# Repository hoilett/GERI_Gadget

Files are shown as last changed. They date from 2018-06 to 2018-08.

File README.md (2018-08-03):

# GERI_Gadget (under development so bookmark this page and stay tuned!)

<p align="center">
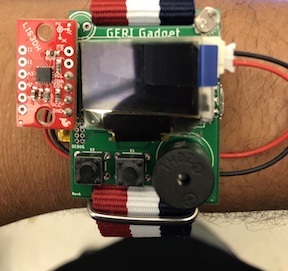
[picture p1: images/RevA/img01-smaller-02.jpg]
GERI Gadget Rev A
  
</p>

The GERI Gadget is a small smartwatch I made for students taking my Biomedical Instrumentation class during GERI Summer Residential 2018. GERI stands for Gifted Education Resource Institute and it's a wonderful group at Purdue that specializes on educational policy, training, teaching methods, etc. of gifted students in K-12. Check out all their wonderful work on their website: [Purdue GERI](https://www.education.purdue.edu/geri/)

Anyways, I wanted to create a device that allowed students to get hands-on experience building some sort of Biomedical device. This meant adding enough peripherals so that students could make anything from a pedometer to even a fall alert. Revision A of the watch contains a few peripherals, namely:
* ATSAMD21 Microcontroller
* On/Off Switch
* Battery Charging Circuit
* OLED
* Two pushbuttons
* Buzzer
* Photoresistor
* LED
* LIS3DH Accelerometer

_**This section is still under development. I will be filling it out over the next few weeks so bookmark this page and stay tuned!**_

## Programming the Microcontroller
###### **A. Installing the board definitions for SparkFun's SAMD21 Dev Breakout Board**
###### **B. Installing the proper code libraries**
You will need three libraries to get started with the GERI Gadget:
1. Adafruit's SSD1306 Library
2. Adafruit's GFX Library
3. SparkFun's LIS3DH Accelerometer Library

## Advanced Setup Instructions
## 1. Assembling the printed circuit board
## 2. Booloading the ATSAMD21

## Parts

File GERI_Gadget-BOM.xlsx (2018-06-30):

GERI Gadget Rev A BOM |  |  |  |  |  |  |  |  |  |  |  | 14 | $25.45 | $356.26 | $21.15 | $22.72 | $318.41 | Totals
BOM # | Comment | Designator | Description | Mounting Type | Package | Manufacturer | Manufacturer Part Number | Supplier | Supplier Part Number | Price per unit | Quantity per Student | Class Quantity (x14) | Total per Student | Class Total | $ per 10 units | $ per 10 units per Student | $ Class total in bulk
1 | SAMD21 | Arduino | ARM® Cortex®-M0+ SAM D21G Microcontroller IC 32-Bit 48MHz 256KB (256K x 8) FLASH 48-TQFP (7x7) | smd | 48-TQFP | Microchip Technology | ATSAMD21G18A-AU | Digikey.com | ATSAMD21G18A-AU-ND | $3.15 | 1 | 14 | $3.15 | $44.10 | $3.15 | $3.15 | $44.10
2 | OLED | OLED | Datasheet 128x64 OLED Module SPI 0.96"Graphic Displays,White on Black | SMD |  | EastRising | ER-OLED0.96-1W | BuyDisplay.com | https://www.buydisplay.com/default/datasheet-128x64-oled-module-spi-0-96-inch-graphic-displays-white-on-black | $3.25 | 1 | 14 | $3.25 | $45.50 | $3.25 | $3.25 | $45.50
3 | MCP6001 | OP1 | General Purpose Amplifier 1 Circuit Rail-to-Rail SOT-23-5 | SMD | SOT-23-5 | Microchip Technology | MCP6001T-I/OT | Digikey.com | MCP6001T-I/OTCT-ND | $0.25 | 1 | 14 | $0.25 | $3.50 | $0.25 | $0.25 | $3.50
4 | Accelerometer | Accel | SparkFun Triple Axis Accelerometer Breakout - LIS3DH | THT |  | SparkFun Electronics | SEN-13963 | SparkFun.com | SEN-13963 | $4.95 | 1 | 14 | $4.95 | $69.30 | $4.95 | $4.95 | $69.30
5 | N-FET |  | N-Channel 60V 260mA (Ta) 300mW (Ta) Surface Mount SOT-23-3 (TO-236) | SMD | SOT-23-3 | ON Semiconductor | NTR5103NT1G | Digikey.com | NTR5103NT1GOSCT-ND | $0.18 | 2 | 28 | $0.36 | $5.04 | $0.16 | $0.32 | $4.51
6 | 400mAh LiPo Battery |  | 3.7V Lithium-Ion Battery Rechargeable (Secondary) 400mAh | JST |  | SparkFun Electronics | PRT-13851 | Digikey.com | 1568-1493-ND | $4.95 | 1 | 14 | $4.95 | $69.30 | $4.95 | $4.95 | $69.30
7 | JST Connector | LIPO | JST Right Angle Connector - White | SMD | NA | 4UCOM Technology Inc. |  | SparkFun.com | PRT-08612 | $0.95 | 1 | 14 | $0.95 | $13.30 | $0.95 | $0.95 | $13.30
8 | MCP73831 | CHRG | Charger IC Lithium-Ion/Polymer SOT-23-5 | SMD | SOT-23-5 | Microchip Technology | MCP73831T-2ACI/OT | Digikey.com | MCP73831T-2ACI/OTCT-ND | $0.58 | 1 | 14 | $0.58 | $8.12 | $0.58 | $0.58 | $8.12
9 | MIC5501-3V | LDO | Linear Voltage Regulator IC Positive Fixed 1 Output 3V 300mA SOT-23-5 | SMD | SOT-23-5 | Microchip Technology | MIC5501-3.0YM5-TR | Digikey.com | 576-4905-1-ND | $0.11 | 1 | 14 | $0.11 | $1.54 | $0.11 | $0.11 | $1.54
10 | Micro USB Female | USB | USB - micro B USB 2.0 Receptacle Connector 5 Position Surface Mount, Right Angle | SMD | 5-Pin-USB-Micro | Amphenol FCI | 10118192-0001LF | Digikey.com | 609-4613-1-ND | $0.46 | 1 | 14 | $0.46 | $6.44 | $0.39 | $0.39 | $5.50
11 | Schottky Diode | D3,D4 | Diode Schottky 30V 1.5A Surface Mount USC | SMD | USC | Toshiba Semiconductor and Storage | CUS15S30,H3F | Digikey.com | CUS15S30H3FCT-ND | $0.43 | 3 | 42 | $1.29 | $18.06 | $0.31 | $0.93 | $13.06
12 | Switch | SWITCH | SWITCH SLIDE DPDT 300MA 6V | SMD | J Lead | C&K | JS202011JCQN | Digikey.com | CKN10723CT-ND | $0.48 | 1 | 14 | $0.48 | $6.72 | $0.46 | $0.46 | $6.48
13 | 15pF capacitor |  | 15pF ±5% 16V Ceramic Capacitor C0G, NP0 0402 (1005 Metric) | SMD | 0402 | Wurth Electronics Inc. | 885012005026 | Digikey.com | 732-7442-1-ND | $0.10 | 2 | 28 | $0.20 | $2.80 | $0.01 | $0.03 | $0.42
14 | 32.768kHz Crystal | Y1,XTAL1 | 32.768kHz ±10ppm Crystal 12.5pF 90 kOhms 2-SMD, No Lead | SMD | 2-SMD, No Lead | ECS Inc. | ECS-.327-12.5-12-C-TR | Digikey.com | XC2288CT-ND | $0.74 | 1 | 14 | $0.74 | $10.36 | $0.74 | $0.74 | $10.36
15 | Inductor | L1 | FERRITE BEAD 220 OHM 0603 1LN | SMD | 0603 | Samsung Electro-Mechanics | CIS10P221NC | Digikey.com | 1276-6350-1-ND | $0.10 | 1 | 14 | $0.10 | $1.40 | $0.10 | $0.10 | $1.40
16 | 40-pos, Male Headers |  | Connector Header Through Hole 40 position 0.100" (2.54mm) | THT |  | Sullins Connector Solutions | PREC040SAAN-RC | Digikey.com | S1012EC-40-ND | $0.51 | 0.25 | 3.5 | $0.13 | $1.79 | $0.51 | $0.10 | $1.79
 | 2.2uF capacitor | C1,C2,C4,C5,C8 | 2.2µF ±20% 10V Ceramic Capacitor X5R 0603 (1608 Metric) | SMD | 0603 | Wurth Electronics Inc. | 885012106011 | Digi-Key | 732-7908-1-ND | $0.10 | 6 | 84 | $0.60 | $8.40 | $0.06 | $0.36 | $5.04
 | 1.02k resistor | R1,R2,R3 | RES SMD 1.02K OHM 1% 1/16W 0402 | SMD | 0402 | Yageo | RC0402FR-071K02L | Digi-Key | YAG3029CT-ND | $0.10 | 4 | 56 | $0.40 | $5.60 | $0.01 | $0.05 | $0.73
 | 10.2k resistor | R3 | 10.2k Ohm ±1% 0.063W, 1/16W Chip Resistor 0402 (1005 Metric) Moisture Resistant Thick Film | SMD | 0402 | Yageo | RC0402FR-0710K2L | Digi-Key | YAG2950CT-ND | $0.10 | 6 | 84 | $0.60 | $8.40 | $0.01 | $0.08 | $1.09
 | 390k resistor
 | 100n capacitor | C3,C5,C7,C8,C9 | 0.1µF ±20% 10V Ceramic Capacitor X5R 0402 (1005 Metric) | SMD | 0402 | KEMET | C0402C104M8PACTU | Digi-Key | 399-7764-1-ND | $0.10 | 8 | 112 | $0.80 | $11.20 | $0.03 | $0.20 | $2.80
 | 10uF capacitor |  | 10µF ±20% 10V Ceramic Capacitor X5R 0603 (1608 Metric) | SMD | 0603 | Taiyo Yuden | LMK107BBJ106MALT | Digi-Key | 587-3258-1-ND | $0.22 | 5 | 70 | $1.10 | $15.40 | $0.15 | $0.76 | $10.57

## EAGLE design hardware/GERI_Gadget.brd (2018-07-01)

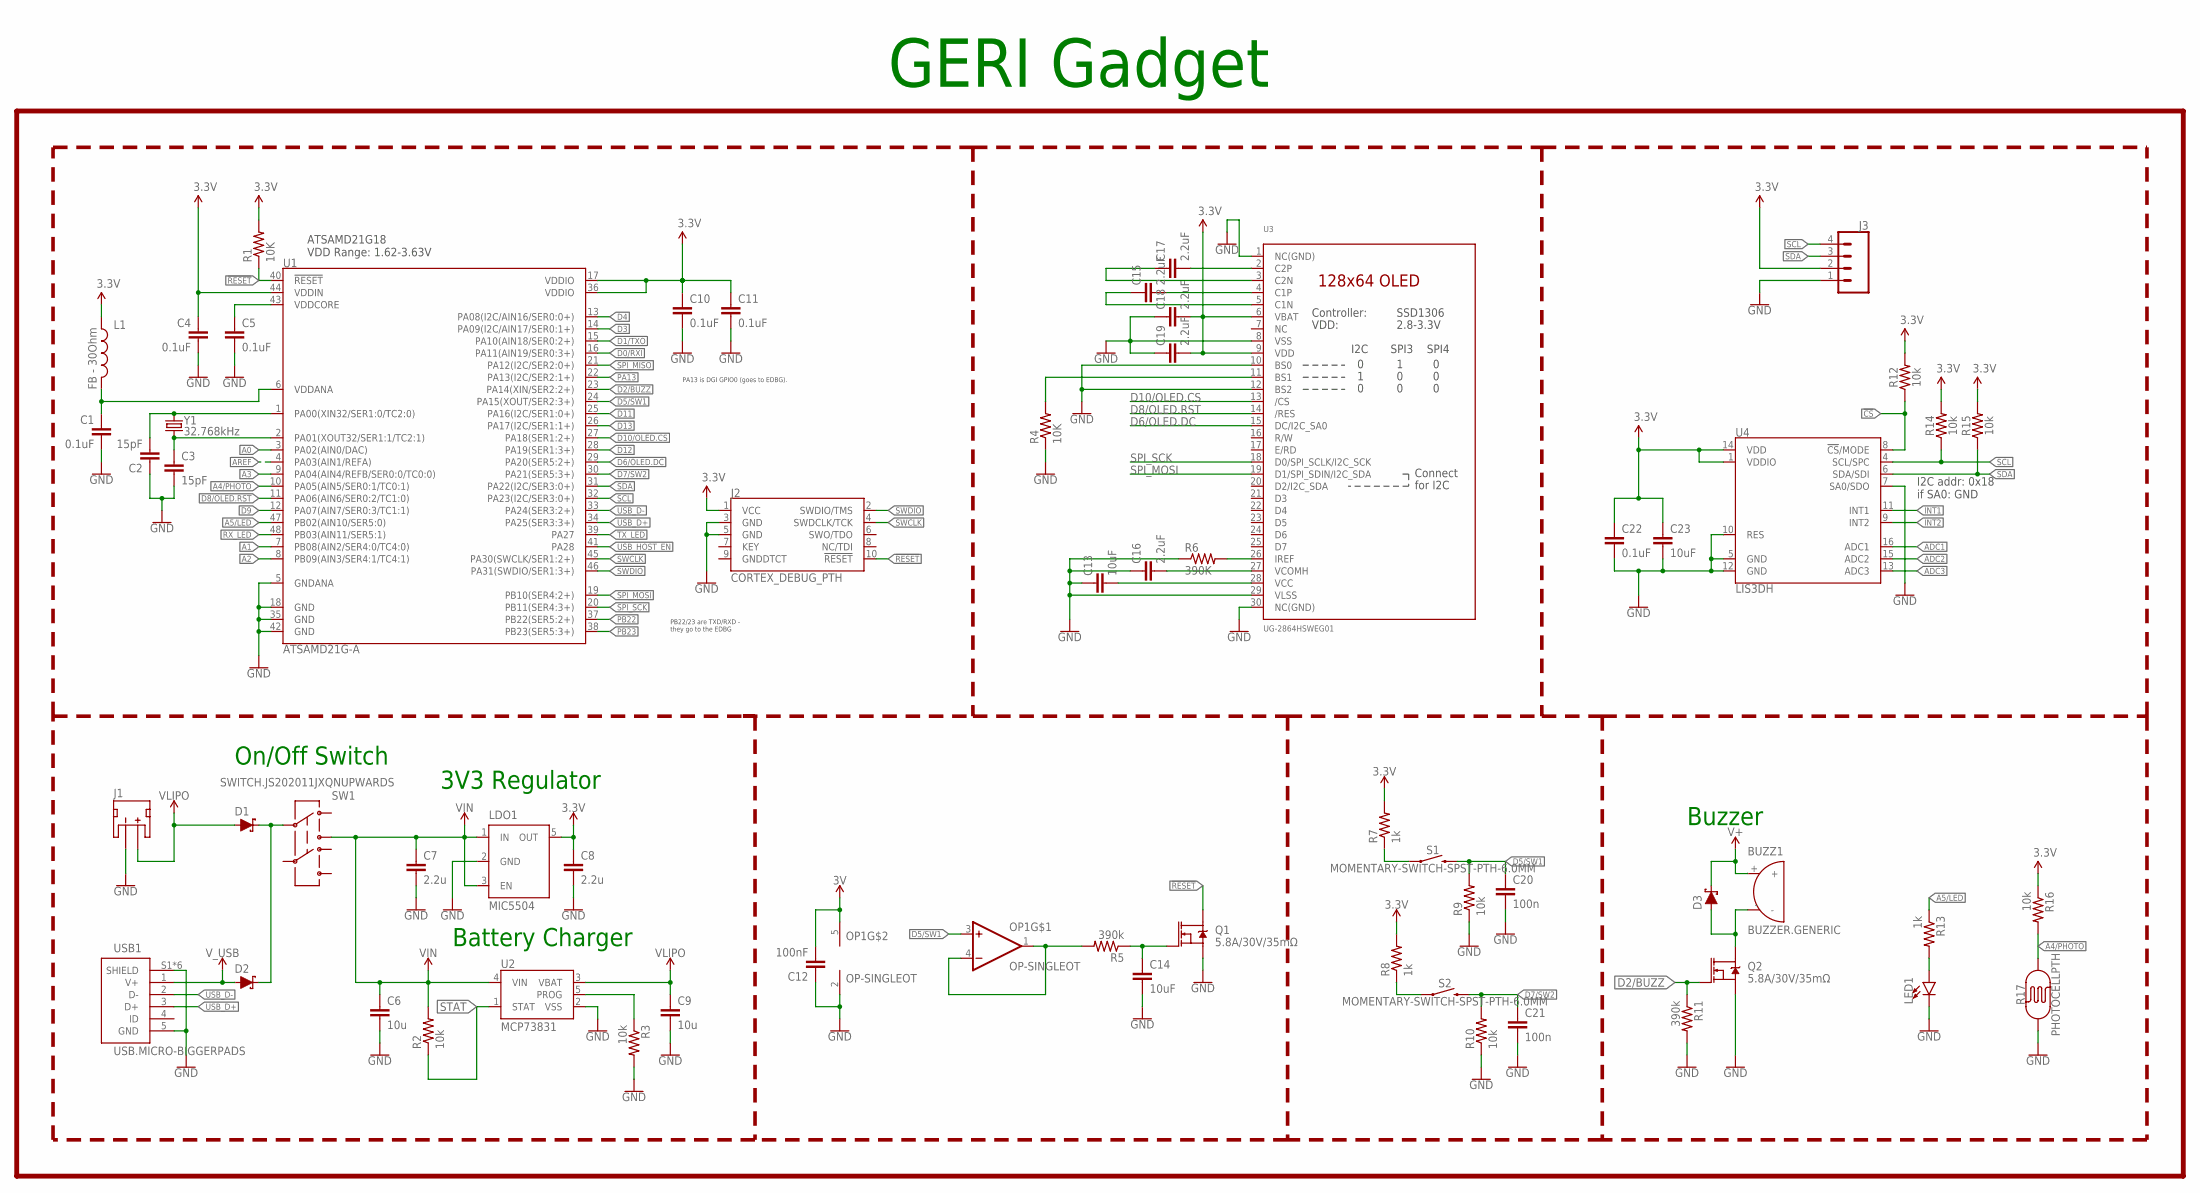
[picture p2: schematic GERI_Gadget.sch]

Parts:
BUZZ1: BUZZER.GENERIC; PIEZO-1
C1, C4, C5, C10, C11: 0.1uF; C0402
C2, C3: 15pF; C0402
C6, C9: 10u; C0603
C7, C8: 2.2u; C0603
C12: 100nF; C0402
C13, C14: 10uF; C0603
C15, C16, C17, C18, C19: 2.2uF; C0603
C20, C21: 100n; C0402
C22: 0.1uF; 0402
C23: 10uF; 0603
D1, D2, D3: SCHOTTKY-USC; USC
J1: JST_2MM_MALE; JST-2-SMD
J2: CORTEX_DEBUG_PTH; 2X5-PTH-1.27MM
J3: CONN_04; 1X04
L1: FB - 30Ohm; 0603
LDO1: MIC5504; SOT23-5
LED1: LED5MM; LED_5MM
OP1: OP-SINGLEOT; SOT23-5
Q1, Q2: 5.8A/30V/35mΩ; SOT23-3
R1, R4: 10K; R0402-BIGGER
R2, R3, R9, R10, R16: 10k; R0402-BIGGER
R5, R11: 390k; R0402-BIGGER
R6: 390K; R0402-BIGGER
R7, R8, R13: 1k; R0402-BIGGER
R12, R14, R15: 10k; 0402
R17: PHOTOCELLPTH; PHOTOCELL
REV1: REVISION.A; REV.A
S1, S2: MOMENTARY-SWITCH-SPST-PTH-6.0MM; TACTILE_SWITCH_PTH_6.0MM
SW1: SWITCH.JS202011JXQNUPWARDS; SWITCH.00
U1: ATSAMD21G-A; TQFP-48
U2: MCP73831; SOT23-5
U3: UG-2864HSWEG01; UG-2864HSWEG01_0.96IN_NO-WRAPAROUND
U4: LIS3DH; LGA-16-3X3
USB1: USB.MICRO-BIGGERPADS; USB-MICRO-01.BIGGERPADS
Y1: 32.768kHz; CRYSTAL-SMD-3.2X1.5MM

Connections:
3.3V: C4.1, C8.1, C10.1, C11.1, C18.2, C19.2, C22.1, C23.1, J2.1 (VCC), J3.2, L1.1, LDO1.5 (OUT), R1.2, R7.2, R8.2, R12.2, R14.2, R15.2, R16.1, U1.17 (VDDIO), U1.36 (VDDIO), U1.44 (VDDIN), U3.6 (VBAT), U3.9 (VDD), U4.1 (VDDIO), U4.14 (VDD)
3V: C12.2, OP1.5 (V+)
!CS: R12.1, U4.8 (!CS!/MODE)
!RESET: J2.10 (!RESET), Q1.3 (D), R1.1, U1.40 (!RESET!)
A0: U1.3 (PA02(AIN0/DAC))
A1: U1.7 (PB08(AIN2/SER4:0/TC4:0))
A2: U1.8 (PB09(AIN3/SER4:1/TC4:1))
A3: U1.9 (PA04(AIN4/REFB/SER0:0/TC0:0))
A4/PHOTO: R16.2, R17.2, U1.10 (PA05(AIN5/SER0:1/TC0:1))
A5/LED: R13.1, U1.47 (PB02(AIN10/SER5:0))
ADC1: U4.16 (ADC1)
ADC2: U4.15 (ADC2)
ADC3: U4.13 (ADC3)
AREF: U1.4 (PA03(AIN1/REFA))
D0/RXI: U1.16 (PA11(AIN19/SER0:3+))
D1/TXO: U1.15 (PA10(AIN18/SER0:2+))
D2/BUZZ: Q2.1 (G), R11.1, U1.23 (PA14(XIN/SER2:2+))
D3: U1.14 (PA09(I2C/AIN17/SER0:1+))
D4: U1.13 (PA08(I2C/AIN16/SER0:0+))
D5/SW1: C20.1, OP1.3 (+IN), R9.2, S1.3 (2), U1.24 (PA15(XOUT/SER2:3+))
D6/OLED.DC: U1.29 (PA20(SER5:2+)), U3.15 (DC/I2C_SA0)
D7/SW2: C21.1, R10.2, S2.3 (2), U1.30 (PA21(SER5:3+))
D8/OLED.RST: U1.11 (PA06(AIN6/SER0:2/TC1:0)), U3.14 (/RES)
D9: U1.12 (PA07(AIN7/SER0:3/TC1:1))
D10/OLED.CS: U1.27 (PA18(SER1:2+)), U3.13 (/CS)
D11: U1.25 (PA16(I2C/SER1:0+))
D12: U1.28 (PA19(SER1:3+))
D13: U1.26 (PA17(I2C/SER1:1+))
GND: C1.2, C2.1, C3.2, C4.2, C5.2, C6.2, C7.2, C8.2, C9.2, C10.2, C11.2, C12.1, C13.1, C14.2, C16.1, C18.1, C19.1, C20.2, C21.2, C22.2, C23.2, J1.1 (-), J2.3 (GND), J2.5 (GND), J3.1, LDO1.2 (GND), LED1.K (C), OP1.2 (V-), Q1.2 (S), Q2.2 (S), R3.2, R4.1, R6.1, R9.1, R10.1, R11.2, R17.1, U1.5 (GNDANA), U1.18 (GND), U1.35 (GND), U1.42 (GND), U2.2 (VSS), U3.1 (NC(GND)), U3.8 (VSS), U3.10 (BS0), U3.12 (BS2), U3.29 (VLSS), U3.30 (NC(GND)), U4.5 (GND), U4.7 (SA0/SDO), U4.10 (RES), U4.12 (GND), USB1.5 (GND), USB1.S1 (SHIELD), USB1.S2 (SHIELD), USB1.S3 (SHIELD), USB1.S4 (SHIELD), USB1.S5 (SHIELD), USB1.S6 (SHIELD)
INT1: U4.11 (INT1)
INT2: U4.9 (INT2)
unnamed: C2.2, U1.1 (PA00(XIN32/SER1:0/TC2:0)), Y1.P$2 (2)
unnamed: LED1.A, R13.2
unnamed: C3.1, U1.2 (PA01(XOUT32/SER1:1/TC2:1)), Y1.P$1 (1)
unnamed: OP1.1 (OUT), OP1.4 (-IN), R5.2
unnamed: R7.1, S1.1
unnamed: R8.1, S2.1
unnamed: R3.1, U2.5 (PROG)
unnamed: D1.- (C), D2.- (C), SW1.2
unnamed: C14.1, Q1.1 (G), R5.1
unnamed: R4.2, U3.11 (BS1)
unnamed: BUZZ1.-, D3.+ (A), Q2.3 (D)
unnamed: R6.2, U3.26 (IREF)
unnamed: C17.2, U3.2 (C2P)
unnamed: C17.1, U3.3 (C2N)
unnamed: C15.2, U3.4 (C1P)
unnamed: C15.1, U3.5 (C1N)
unnamed: C13.2, U3.28 (VCC)
unnamed: C16.2, U3.27 (VCOMH)
PA13: U1.22 (PA13(I2C/SER2:1+))
PB22: U1.37 (PB22(SER5:2+))
PB23: U1.38 (PB23(SER5:3+))
RX_LED: U1.48 (PB03(AIN11/SER5:1))
SCL: J3.4, R14.1, U1.32 (PA23(I2C/SER3:0+)), U4.4 (SCL/SPC)
SDA: J3.3, R15.1, U1.31 (PA22(I2C/SER3:0+)), U4.6 (SDA/SDI)
SPI_MISO: U1.21 (PA12(I2C/SER2:0+))
SPI_MOSI: U1.19 (PB10(SER4:2+)), U3.19 (D1/SPI_SDIN/I2C_SDA)
SPI_SCK: U1.20 (PB11(SER4:3+)), U3.18 (D0/SPI_SCLK/I2C_SCK)
STAT: R2.1, U2.1 (STAT)
SWCLK: J2.4 (SWDCLK/TCK), U1.45 (PA30(SWCLK/SER1:2+))
SWDIO: J2.2 (SWDIO/TMS), U1.46 (PA31(SWDIO/SER1:3+))
TX_LED: U1.39 (PA27)
USB_D+: U1.34 (PA25(SER3:3+)), USB1.3 (D+)
USB_D-: U1.33 (PA24(SER3:2+)), USB1.2 (D-)
USB_HOST_EN: U1.41 (PA28)
V+: BUZZ1.+, D3.- (C)
VDDANA: C1.1, L1.2, U1.6 (VDDANA)
VDDCORE: C5.1, U1.43 (VDDCORE)
VIN: C6.1, C7.1, LDO1.1 (IN), LDO1.3 (EN), R2.2, SW1.3, U2.4 (VIN)
VLIPO: C9.1, D1.+ (A), J1.2 (+), U2.3 (VBAT)
V_USB: D2.+ (A), USB1.1 (V+)

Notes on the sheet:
PB22/23 are TXD/RXD - they go to the EDBG
PA13 is DGI GPIO0 (goes to EDBG).
ATSAMD21G18 VDD Range: 1.62-3.63V
3V3 Regulator
On/Off Switch
Battery Charger
Buzzer
I2C addr: 0x18 if SA0: GND
GERI Gadget

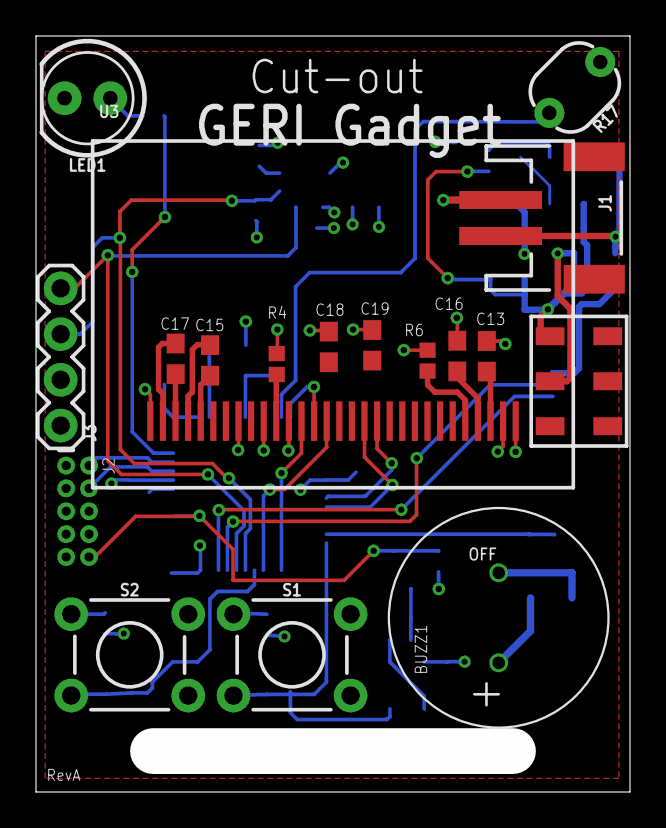
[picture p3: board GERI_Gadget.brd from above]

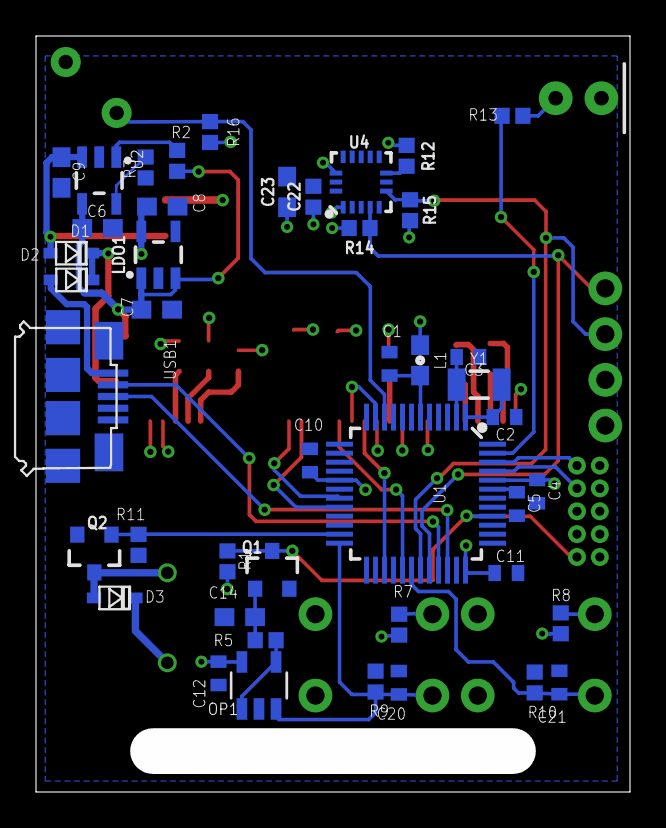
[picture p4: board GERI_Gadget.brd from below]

Board: 2 copper layers, 33.0 x 42.0 mm, 63 parts (44 on the bottom side), 46 nets.

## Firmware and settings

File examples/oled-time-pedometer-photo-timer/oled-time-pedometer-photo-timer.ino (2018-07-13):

#include <SPI.h>
#include <Wire.h>
#include <Adafruit_GFX.h>
#include <Adafruit_SSD1306.h>

// Uncomment this block to use hardware SPI
#define OLED_DC     6
#define OLED_CS     10
#define OLED_RESET  8
Adafruit_SSD1306 display(OLED_DC, OLED_RESET, OLED_CS);

#define NUMFLAKES 10
#define XPOS 0
#define YPOS 1
#define DELTAY 2

#define LOGO16_GLCD_HEIGHT 16 
#define LOGO16_GLCD_WIDTH  16 
static const unsigned char PROGMEM logo16_glcd_bmp[] =
{ B00000000, B11000000,
  B00000001, B11000000,
  B00000001, B11000000,
  B00000011, B11100000,
  B11110011, B11100000,
  B11111110, B11111000,
  B01111110, B11111111,
  B00110011, B10011111,
  B00011111, B11111100,
  B00001101, B01110000,
  B00011011, B10100000,
  B00111111, B11100000,
  B00111111, B11110000,
  B01111100, B11110000,
  B01110000, B01110000,
  B00000000, B00110000 };

#if (SSD1306_LCDHEIGHT != 64)
#error("Height incorrect, please fix Adafruit_SSD1306.h!");
#endif

//this is for the screen
int screenNumber = 0;


//This is for the pedometer
#include "SparkFunLIS3DH.h"
#include "Wire.h"
#include "SPI.h"
LIS3DH myIMU; //Default constructor is I2C, addr 0x19.
unsigned long steps = 0;


//This is for the time
#include <RTCZero.h>
RTCZero rtc;
/* Change these values to set the current initial time */
const byte seconds = 0;
const byte minutes = 7;
const byte hours = 10;

/* Change these values to set the current initial date */
const byte day = 15;
const byte month = 6;
const byte year = 15;


//this is for the graph
int xaxis = 0;


//this is for the timer
unsigned long counter = 0;
unsigned long startTime = 0;

void setup()   {                
  SerialUSB.begin(9600);


  //this is for the display
  display.begin(SSD1306_SWITCHCAPVCC);
  display.display();
  delay(2000);
  display.clearDisplay();


  //this is for the time
  rtc.begin();
  rtc.setTime(hours, minutes, seconds);
  rtc.setDate(day, month, year);


  //this is for the step counter / pedometer
  myIMU.begin();
}

void loop()
{
  //this is for the pedometer
  if(myIMU.readFloatAccelX() > 1.2)
  {
    steps++;
    delay(500);
  }

  //this is for reading the button to change the screen
  if(digitalRead(7))
  {
    screenNumber++;
    delay(250);
    if(screenNumber > 3)
    {
      screenNumber = 0;
    }
  }

  //clock screen
  if(screenNumber == 0)
  {
    display.clearDisplay();
    display.setTextSize(2);
    display.setTextColor(WHITE);
    display.setCursor(0,0);
    display.print("Hr: ");
    display.println(rtc.getHours());
    display.print("Min: ");
    display.println(rtc.getMinutes());
    display.print("Sec: ");
    display.println(rtc.getSeconds());
    display.display();
  }

  //pedometer screen
  if(screenNumber == 1)
  {
    display.clearDisplay();
    display.setTextSize(2);
    display.setTextColor(WHITE);
    display.setCursor(0,0);
    display.println("STEPS:");
    display.println(steps);
    display.display();
  }

  //graph screen
  if(screenNumber == 2)
  {
    if(xaxis == 0)
    {
      display.clearDisplay();
    }
    int photo = analogRead(A4);
    photo = map(photo, 0, 1023, 64, 0);
    display.drawPixel(xaxis,photo, WHITE); 
    display.display();
    
    xaxis++;
    if(xaxis > 128)
    {
      xaxis = 0;
    }
  }

  //stopwatch screen
  if(screenNumber == 3)
  {
    if(counter == 0)
    {
      startTime = millis();
    }
    
    unsigned long currentTime = (millis()-startTime)/1000;
    unsigned long stopwatch_minutes = currentTime/60;
    unsigned long stopwatch_seconds = currentTime%60;
    counter++;
    
    display.clearDisplay();
    display.setTextSize(3);
    display.setTextColor(WHITE);
    display.setCursor(0,0);
    display.print(stopwatch_minutes);
    display.print(":");
    if(stopwatch_seconds < 10)
    {
      display.print("0");
      display.println(stopwatch_seconds);
    }
    else
    {
      display.println(stopwatch_seconds);
    }
    display.display();
  }

  if(screenNumber != 3) counter = 0;
}

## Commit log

2018-06-30 still working on these
    [GERI_Gadget-BOM.xlsx, GERI_Gadget.brd, GERI_Gadget.sch]
2018-07-01 updates...almost done
    [GERI_Gadget.brd, GERI_Gadget.sch]
2018-07-13 fixed issues with taking an extra button push to switch screens
    [oled-pedometer.ino, oled-test.ino, oled-time-pedometer-photo.ino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]

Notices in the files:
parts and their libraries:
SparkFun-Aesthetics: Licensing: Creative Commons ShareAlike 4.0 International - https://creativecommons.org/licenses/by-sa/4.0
